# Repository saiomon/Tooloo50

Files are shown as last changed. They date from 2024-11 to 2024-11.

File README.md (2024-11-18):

# Tooloo50
Töölöö50 is 40% tadpole mount keyboard with arrow cluster/40%TKL/numpad.

## Layout
Supports iso/ansi enter, split right shift, wk/wkl, a few bottom row options and 4x3 grid on the right hand side extension.
töölöö50

## Case
3DP case files support some of the possible combinations.
render
vid

### Hardware list
| Item | Amount |
| --- | --- |
| Tadpole | 8 |
| M2.5 10mm | 2 |
| M2.5 16mm (CS)  | 2 |
| M2.5 6mm  (CS) | 2 |
| M2.5 Heat insert, OD 3.5mm | 6 |

*Countersunk (CS)

## PCB
PCB supports mx switches, and additionally 4-key hall sensors on wasd for HE option. STM32F072 processor, ESD protection, fuse, smd USB. Possibility for external flash and crystal. KiCad files and production files are included.
TooLooMX

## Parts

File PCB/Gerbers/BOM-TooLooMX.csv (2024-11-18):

Comment | Designator | Footprint | LCSC
100k | R3,R4 | R_0805_2012Metric | C149504
10n | C9 | C_0402_1005Metric | C15195
100n | C1,C11,C13,C14,C15,C16,C17,C18,C19,C20,C21,C22,C23,C4,C5 | C_0402_1005Metric | C1525
TYPE-C-31-M12 | J1 | USB_C_Receptacle_Hroparts_TYPE-C-31-M-12 | C165948
220 | R14,R15 | R_0805_2012Metric | C17557
D_Schottky | D63 | D_SOD-123F | C18199087
2N7002K | Q1 | SOT-23 | C22379475
10k | R10,R11,R12,R13,R9 | R_0402_1005Metric | C25744
51k | R6 | R_0402_1005Metric | C25794
1.5k | R5 | R_0402_1005Metric | C25867
4.7k | R1,R2 | R_0402_1005Metric | C25900
5.1k | R7,R8 | R_0805_2012Metric | C27834
1u | C2,C3 | C_0805_2012Metric | C28323
SLSS49E-3 | HALL1,HALL2,HALL3,HALL4 | SOT-23 | C2904393
STM32F401-LQFP64 | U2 | LQFP-64_10x10mm_P0.5mm | C46046
1u | C8 | C_0402_1005Metric | C52923
MCP1700T-3302E/TT | U1 | SOT-23 | C5446
mSMD110-16V | F1,F2,F3 | Fuse_1812_4532Metric | C69691
10u | C10 | CP_EIA-3216-10_Kemet-I_Pad1.58x1.35mm_HandSolder | C7171
1N4148W | D1,D10,D11,D12,D13,D14,D15,D16,D17,D18,D19,D2,D20,D21,D22,D23,D24,D25,D26,D27,D28,D29,D3,D30,D31,D32,D33,D34,D35,D36,D37,D38,D39,D4,D40,D41,D42,D43,D44,D45,D46,D47,D48,D49,D5,D50,D51,D52,D53,D54,D55,D56,D57,D58,D59,D6,D60,D61,D7,D8,D9 | D_SOD-123 | C81598
SRV05-4-P-T7 | U3 | SOT-23-6-routable | C85364
RB060M-60TR SS34 | D62 | D_SMA | C8678

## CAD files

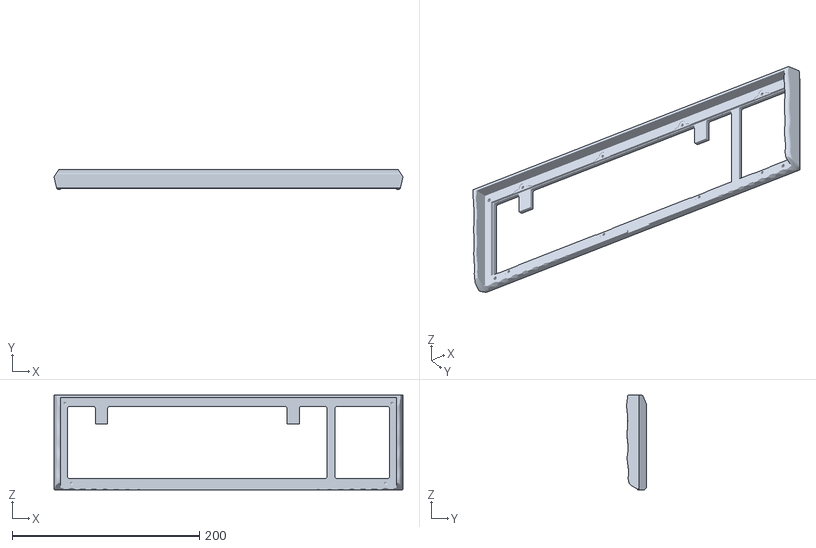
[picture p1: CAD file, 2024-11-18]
Case/stl/TopWKL_FullGrid.stl
373.0 x 21.3 x 101.2

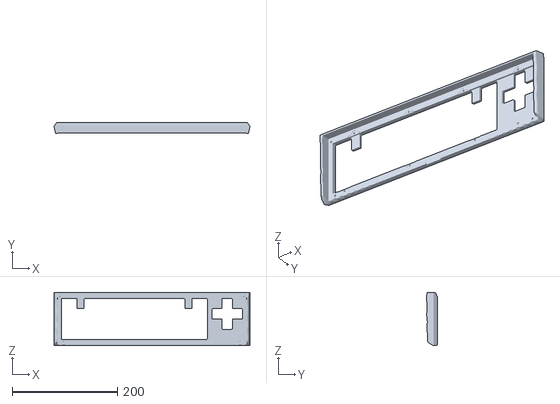
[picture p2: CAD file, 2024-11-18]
Case/stl/TopWKL_Arrows.stl
373.0 x 21.3 x 101.2

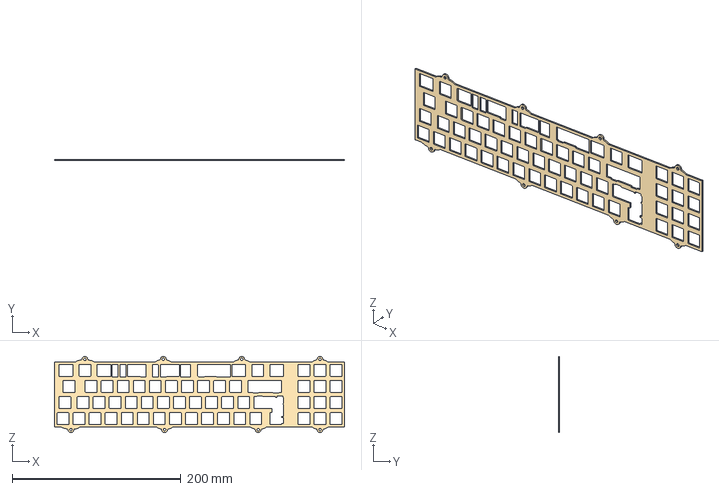
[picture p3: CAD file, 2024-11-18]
Case/step/plate.step
343.9 x 1.60 x 90.3 mm

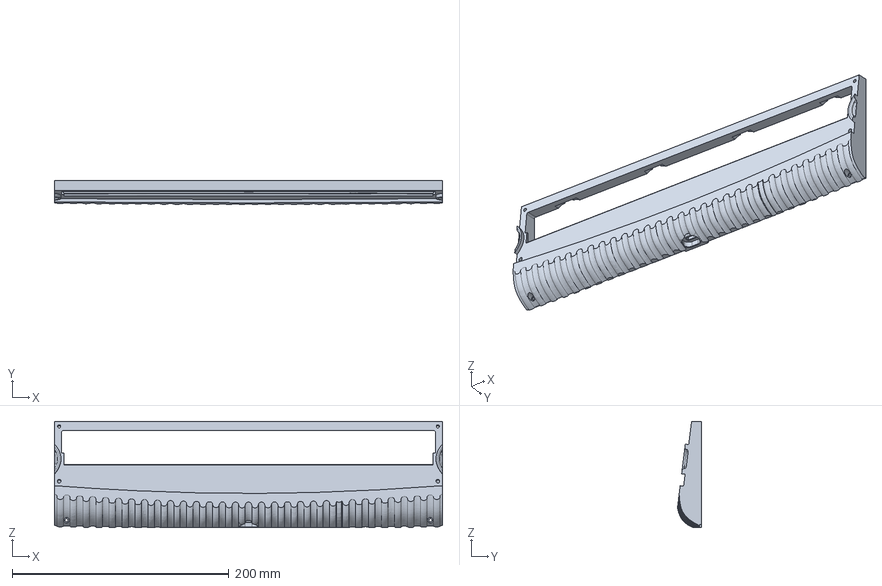
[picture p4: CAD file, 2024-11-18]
Case/step/Bottom.step
358.1 x 22.3 x 98.3 mm

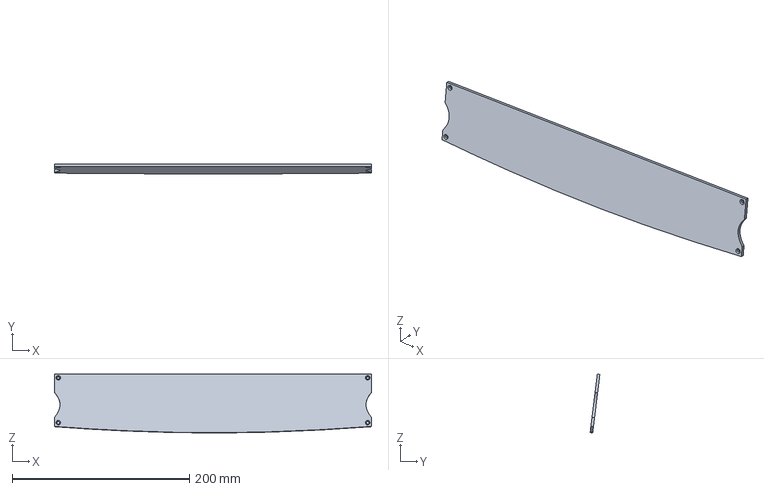
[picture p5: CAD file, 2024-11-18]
Case/step/Weight.step
358.1 x 11.1 x 66.6 mm

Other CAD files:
Case/step/TopTKL_FullGrid.step
Case/step/TopWKL_TKL.step
Case/step/TopTKL_arrows.step
Case/stl/TopWKL_TKL.stl
Case/stl/Weight.stl

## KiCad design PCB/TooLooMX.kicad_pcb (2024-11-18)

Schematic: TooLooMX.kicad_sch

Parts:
BOOT1: Jumper_2_Open; SolderJumper-2_P1.3mm_Open_Pad1.0x1.5mm
BZ1: Buzzer; MagneticBuzzer_PUI_AT-0927-TT-6-R; not fitted
C1, C4: 100n; C_0402_1005Metric; Manufacturer Part Number CC0402KRX7R8BB104
C2, C3: 1u; C_0805_2012Metric; Manufacturer Part Number CC0805KKX7R8BB105
C5, C11, C13, C15, C16, C17, C18, C19, C20, C21, C22, C23: 100n; C_0402_1005Metric
C6, C7: 16p; C_0402_1005Metric; not fitted
C8: 1u; C_0402_1005Metric
C9: 10n; C_0402_1005Metric
C10: 10u; CP_EIA-3216-10_Kemet-I_Pad1.58x1.35mm_HandSolder; Manufacturer Part Number TAJA106K016RNJ
C12: 4.7u; C_0402_1005Metric; not fitted
C14: 100n; C_0402_1005Metric; Manufacturer Part Number CL05B104KB54PNC
D1, D2, D3, D4, D5, D6, D7, D8, D9, D10, D11, D12, D13, D14, D15, D16, D17, D18, D19, D20, D21, D22, D23, D24, D25, D26, D27, D28, D29, D30, D31, D32, D33, D34, D35, D36, D37, D38, D39, D40, D41, D42, D43, D44, D45, D46, D47, D48, D49, D50, D51, D52, D53, D54, D55, D56, D57, D58, D59, D60, D61: 1N4148W; D_SOD-123; Manufacturer Part Number 1N4148W
D62: RB060M-60TR SS34; D_SMA; Manufacturer Part Number RB060M-60TR SS34
D63: D_Schottky; D_SOD-123F
F1, F2, F3: mSMD110-16V; Fuse_1812_4532Metric; Manufacturer Part Number mSMD110-16V
FB1: CBW201209U121T; L_0805_2012Metric; Manufacturer Part Number CBW201209U121T
HALL1, HALL2, HALL3, HALL4: SLSS49E-3; SOT-23
J1: TYPE-C-31-M12; USB_C_Receptacle_Hroparts_TYPE-C-31-M-12; Manufacturer Part Number TYPE-C-31-M-12
M1: Motor_DC; Buzzer_15x7.5RM7.6; not fitted
NRST1: Jumper_2_Open; SolderJumper-2_P1.3mm_Open_Pad1.0x1.5mm
Q1: 2N7002K; SOT-23
Q2: TIP120; TO-220-3_Vertical; not fitted
R1, R2: 4.7k; R_0402_1005Metric
R3, R4: 100k; R_0805_2012Metric; Manufacturer Part Number RC0805FR-07100KL
R5: 1.5k; R_0402_1005Metric
R6: 51k; R_0402_1005Metric
R7, R8: 5.1k; R_0805_2012Metric; Manufacturer Part Number RC0805FR-075K1L
R9: 10k; R_0402_1005Metric; Manufacturer Part Number 0402WGF1002TCE
R10, R11, R12, R13: 10k; R_0402_1005Metric
R14, R15: 220; R_0805_2012Metric
S1: MX_stab; STAB_MX_P_10u
S2, S4: MX_stab; STAB_MX_P_3u
S3: MX_stab; STAB_MX_P_2.25u
S5: MX_stab; STAB_MX_2u
S6: MX_stab; STAB_MX_P_2.75u
S7: MX_stab; STAB_MX_2.75u
S8: MX_stab; STAB_MX_2.25u
S9: MX_stab; STAB_MX_P_ISO-ROT
SW1, SW2, SW3, SW4, SW5, SW6, SW7, SW8, SW9, SW10, SW11, SW12, SW13, SW14, SW15, SW16, SW18, SW20, SW21, SW22, SW23, SW24, SW25, SW26, SW27, SW28, SW29, SW30, SW31, SW32, SW33, SW34, SW35, SW37, SW38, SW39, SW40, SW41, SW42, SW43, SW44, SW45, SW46, SW47, SW49, SW50, SW51, SW56, SW57, SW58, SW62, SW63, SW64, SW67, SW68, SW69: CPG151101S11; SW_MX_1u; Manufacturer Part Number CPG151101S11
SW17, SW48, SW65, SW66, SW70, SW71: CPG151101S11; SW_MX_1.5u; Manufacturer Part Number CPG151101S11
SW19, SW52, SW53, SW54, SW55, SW59, SW60, SW61: CPG151101S11; SW_MX_1.25u; Manufacturer Part Number CPG151101S11
SW36: CPG151101S11; SW_MX_1.75u; Manufacturer Part Number CPG151101S11
U1: MCP1700T-3302E/TT; SOT-23; Manufacturer Part Number MCP1700T-3302E/TT
U2: STM32F401-LQFP64; LQFP-64_10x10mm_P0.5mm
U3: SRV05-4-P-T7; SOT-23-6-routable; Manufacturer Part Number USBLC6-2SC6
U4: BL24C256A-SFRC; TSSOP-8_4.4x3mm_P0.65mm; Manufacturer Part Number BL24C256A-SFRC; not fitted
X1: ARM JTAG; PinHeader_2x5_P2.54mm_Vertical_Staggered
X2: LED; PinHeader_1x2_P2.54mm_Vertical
Y1: 7325-0800A2010-00; Crystal_SMD_3225-4Pin_3.2x2.5mm; Manufacturer Part Number 7325-0800A2010-00; not fitted

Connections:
3V3: BOOT1.1 (A), C1.2, C3.1, C4.1, C5.2, C8.1, C9.1, C10.1, C11.2, C13.2, C15.2, C17.2, C19.2, C21.2, C23.2, D62.2 (A), HALL1.1 (VDD), HALL2.1 (VDD), HALL3.1 (VDD), HALL4.1 (VDD), R1.1, R2.1, R4.1, R5.1, R6.1, U1.2 (VO), U2.1 (VBAT), U2.13 (VDDA/VREF+), U2.19 (VDD), U2.32 (VDD), U2.48 (VDD), U2.64 (VDD), U4.8 (VCC), X1.7, X1.8
5V: C2.1, D62.1 (K), D63.1 (K), F1.2, M1.1 (+), R3.1, U1.3 (VI)
AI0: C16.1, R10.1, U2.24 (PC4)
AI1: C18.1, R11.1, U2.25 (PC5)
AI2: C20.1, R12.1, U2.26 (PB0/TIM3_CH3)
AI3: C22.1, R13.1, U2.27 (PB1/TIM3_CH4)
BOOT0: BOOT1.2 (B), R9.2, U2.60 (BOOT0), X1.5
BUZ: R15.1, U2.41 (USART1_CK/TIM1_CH1/PA8)
C0: SW1.1, SW2.1, SW19.1, SW36.1, U2.23 (PA7/SPI1_MOSI/TIM3_CH2)
C1: SW3.1, SW20.1, SW37.1, SW53.1, SW65.1, U2.22 (PA6/TIM3_CH1/SPI1_MISO)
C2: SW4.1, SW21.1, SW38.1, SW54.1, U2.21 (PA5/TIM2_CH1/SPI1_SCK)
C3: SW5.1, SW22.1, SW39.1, SW55.1, SW66.1, U2.20 (PA4/USART2_CK)
C4: SW6.1, SW23.1, SW40.1, SW56.1, SW67.1, U2.17 (PA3/TIM2_CH4/USART2_RX)
C5: SW7.1, SW24.1, SW41.1, U2.2 (PC13)
C6: SW8.1, SW25.1, SW42.1, SW57.1, SW68.1, U2.3 (PC14/OSC32_IN)
C7: SW9.1, SW26.1, SW43.1, U2.4 (PC15/OSC32_OUT)
C8: SW10.1, SW27.1, SW44.1, SW58.1, SW69.1, U2.8 (PC0)
C9: SW11.1, SW28.1, SW45.1, U2.16 (PA2/TIM2_CH3/USART2_TX)
C10: SW12.1, SW29.1, SW46.1, SW59.1, SW70.1, U2.15 (PA1/TIM2_CH2/USART2_RTS)
C11: SW13.1, SW30.1, SW47.1, SW52.1, SW60.1, U2.14 (PA0/TIM2_CH1/USART2_CTS)
C12: SW17.1, SW18.1, SW31.1, SW35.1, SW48.1, SW61.1, SW71.1, U2.39 (USART6_CK/TIM3_CH3/PC8)
C13: SW14.1, SW32.1, SW49.1, SW62.1, U2.57 (SPI1_MOSI/SPI3_MOSI/TIM3_CH2/PB5)
C14: SW15.1, SW33.1, SW50.1, SW63.1, U2.56 (NJTRST/SPI1_MISO/SPI3_MISO/I2C3_SDA/TIM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)
C15: SW16.2, SW34.2, SW51.2, SW64.2, U2.55 (JTDO-SWO/SPI1_SCK/SPI3_SCK/I2C2_SDA/TIM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)
D+: J1.A6 (D+), J1.B6 (D+), R5.2, U2.45 (OTG_FS_DP/USART6_RX/PA12), U3.1 (IO1)
D-: J1.A7 (D-), J1.B7 (D-), U2.44 (OTG_FS_DM/TIM1_CH4/USART6_TX/PA11), U3.3 (IO2)
GND: BZ1.2 (-), C1.1, C2.2, C3.2, C4.2, C5.1, C6.2, C7.2, C8.2, C9.2, C10.2, C11.1, C12.1, C13.1, C14.2, C15.1, C16.2, C17.1, C18.2, C19.1, C20.2, C21.1, C22.2, C23.1, FB1.1, HALL1.2 (GND), HALL2.2 (GND), HALL3.2 (GND), HALL4.2 (GND), J1.A1 (GND), J1.B1 (GND), NRST1.1 (A), Q1.2 (S), Q2.3 (E), R3.2, R4.2, R7.1, R8.1, R9.1, U1.1 (GND), U2.12 (VSSA/VREF-), U2.18 (VSS), U2.31 (VSS), U2.47 (VSS), U2.63 (VSS), U3.2 (VN), U4.1 (A0), U4.2 (A1), U4.3 (A2), U4.4 (GND), U4.7 (WP), X1.3, X1.4, X1.10, X2.2, Y1.2, Y1.4
GNDPWR: FB1.2, J1.S (SHIELD)
LED_PWM: U2.9 (PC1), X2.1
NRST: C14.1, NRST1.2 (B), U2.7 (NRST), X1.9
unnamed: BZ1.1 (+), R15.2
unnamed: D1.2 (A), SW1.2
unnamed: D2.2 (A), SW2.2
unnamed: D3.2 (A), SW3.2
unnamed: D4.2 (A), SW4.2
unnamed: D5.2 (A), SW5.2
unnamed: D6.2 (A), SW6.2
unnamed: D7.2 (A), SW7.2
unnamed: D8.2 (A), SW8.2
unnamed: D9.2 (A), SW9.2
unnamed: D10.2 (A), SW10.2
unnamed: D11.2 (A), SW11.2
unnamed: D12.2 (A), SW12.2
unnamed: D13.2 (A), SW13.2
unnamed: D14.2 (A), SW14.2
unnamed: D15.2 (A), SW15.2
unnamed: D16.2 (A), SW16.1
unnamed: D17.2 (A), SW17.2, SW18.2
unnamed: D18.2 (A), SW19.2
unnamed: D19.2 (A), SW20.2
unnamed: D20.2 (A), SW21.2
unnamed: D21.2 (A), SW22.2
unnamed: D22.2 (A), SW23.2
unnamed: D23.2 (A), SW24.2
unnamed: D24.2 (A), SW25.2
unnamed: D25.2 (A), SW26.2
unnamed: D26.2 (A), SW27.2
unnamed: D27.2 (A), SW28.2
unnamed: D28.2 (A), SW29.2
unnamed: D29.2 (A), SW30.2
unnamed: D30.2 (A), SW31.2, SW35.2
unnamed: D31.2 (A), SW32.2
unnamed: D32.2 (A), SW33.2
unnamed: D33.2 (A), SW34.1
unnamed: D34.2 (A), SW36.2
unnamed: D35.2 (A), SW37.2
unnamed: D36.2 (A), SW38.2
unnamed: D37.2 (A), SW39.2
unnamed: D38.2 (A), SW40.2
unnamed: D39.2 (A), SW41.2
unnamed: D40.2 (A), SW42.2
unnamed: D41.2 (A), SW43.2
unnamed: D42.2 (A), SW44.2
unnamed: D43.2 (A), SW45.2
unnamed: D44.2 (A), SW46.2
unnamed: D45.2 (A), SW47.2, SW52.2
unnamed: D46.2 (A), SW48.2
unnamed: D47.2 (A), SW49.2
unnamed: D48.2 (A), SW50.2
unnamed: D49.2 (A), SW51.1
unnamed: D50.2 (A), SW53.2, SW65.2
unnamed: D51.2 (A), SW54.2
unnamed: D52.2 (A), SW55.2, SW66.2
unnamed: D53.2 (A), SW56.2, SW67.2
unnamed: D54.2 (A), SW57.2, SW68.2
unnamed: D55.2 (A), SW58.2, SW69.2
unnamed: D56.2 (A), SW59.2, SW70.2
unnamed: D57.2 (A), SW60.2
unnamed: D58.2 (A), SW61.2, SW71.2
unnamed: D59.2 (A), SW62.2
unnamed: D60.2 (A), SW63.2
unnamed: D61.2 (A), SW64.1
unnamed: D63.2 (A), M1.2 (-), Q1.3 (D), Q2.2 (C)
unnamed: HALL1.3 (VOUT), R10.2
unnamed: HALL2.3 (VOUT), R11.2
unnamed: HALL3.3 (VOUT), R12.2
unnamed: HALL4.3 (VOUT), R13.2
unnamed: J1.A5 (CC1), R7.2
unnamed: J1.B5 (CC2), R8.2
unnamed: Q1.1 (G), Q2.1 (B), R14.2
unnamed: R6.2, U2.43 (USART1_RX/TIM1_CH3/PA10)
unnamed: C12.2, U2.30 (VCAP1)
PA9: U2.42 (USART1_TX/TIM1_CH2/PA9)
PB2/BOOT1: U2.28 (PB2), X1.6
PB13: U2.34 (SPI2_SCK/I2S2_CK/PB13)
R0: D2.1 (K), D3.1 (K), D4.1 (K), D5.1 (K), D6.1 (K), D7.1 (K), D8.1 (K), D9.1 (K), D10.1 (K), D11.1 (K), D12.1 (K), D13.1 (K), D14.1 (K), D15.1 (K), D16.1 (K), D17.1 (K), U2.51 (SPI3_SCK/I2S3_CK/PC10)
R1: D18.1 (K), D19.1 (K), D20.1 (K), D21.1 (K), D22.1 (K), D23.1 (K), D24.1 (K), D25.1 (K), D26.1 (K), D27.1 (K), D28.1 (K), D29.1 (K), D30.1 (K), D31.1 (K), D32.1 (K), D33.1 (K), U2.52 (SPI3_MISO/PC11)
R2: D34.1 (K), D35.1 (K), D36.1 (K), D37.1 (K), D38.1 (K), D39.1 (K), D40.1 (K), D41.1 (K), D42.1 (K), D43.1 (K), D44.1 (K), D45.1 (K), D46.1 (K), D47.1 (K), D48.1 (K), D49.1 (K), U2.61 (I2C1_SCL/TIM4_CH3/TIM10_CH1/PB8)
R3: D1.1 (K), D50.1 (K), D51.1 (K), D52.1 (K), D53.1 (K), D54.1 (K), D55.1 (K), D56.1 (K), D57.1 (K), D58.1 (K), D59.1 (K), D60.1 (K), D61.1 (K), U2.62 (I2C1_SDA/TIM4_CH4/TIM11_CH1/PB9)
RGB_3V3: U2.36 (SPI2_MOSI/PB15)
SCL: R2.2, U2.58 (I2C1_SCL/USART1_TX/TIM4_CH1/PB6), U4.6 (SCL)
SDA: R1.2, U2.59 (I2C1_SDA/USART1_RX/TIM4_CH2/PB7), U4.5 (SDA)
SOL: R14.1, U2.50 (JTDI/TIM2_CH1/PA14)
SWCLK: U2.49 (JTCK-SWCLK/PA14), X1.2
SWDIO: U2.46 (JTMS-SWDIO/PA13), X1.1
VBUS: F1.1, J1.A4 (VBUS), J1.B4 (VBUS), U3.5 (VP)
XTAL_IN: C7.1, U2.5 (PH0/OSC_IN), Y1.3
XTAL_OUT: C6.1, U2.6 (PH1/OSC_OUT), Y1.1

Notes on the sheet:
Spooky pin (*)
SWITCH MATRIX
EEPROM
3V3
(*) "Spooky pins": on STM32F4x1, pins A9 and B2 cannot be used for switch matrix: - A9 is meant to be used as a VBUS sensing. It has a undocumented internal pulldown resistor; - B2 is used as BOOT1 during bootup, so it needs an external pulldown for successful bootup; - B13 is locked by the SPI dri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

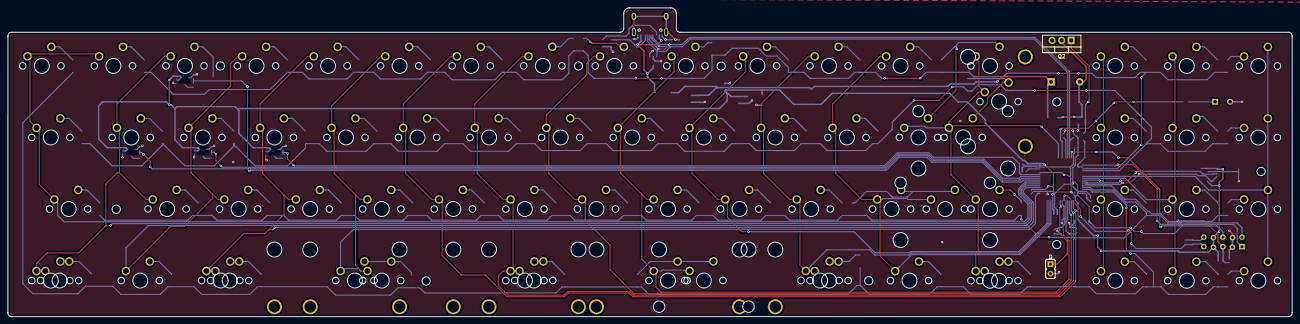
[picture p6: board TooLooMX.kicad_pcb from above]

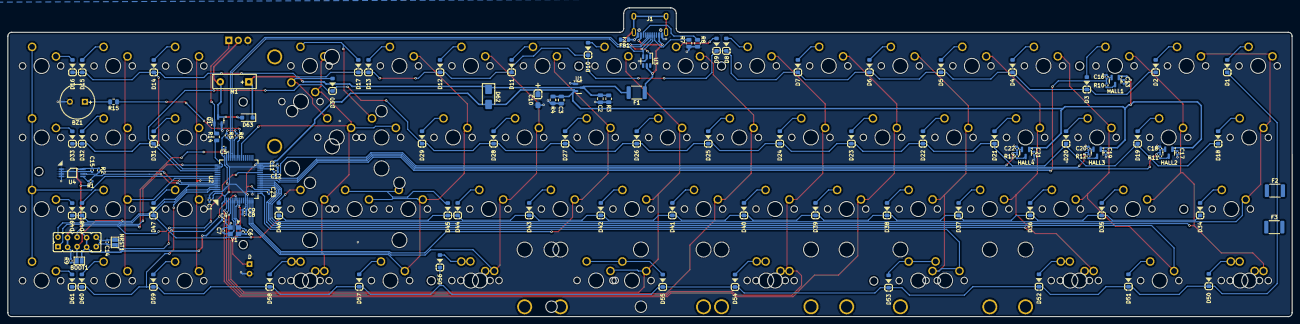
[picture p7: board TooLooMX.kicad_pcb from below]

Board: 2 copper layers, 341.9 x 82.2 mm, 203 parts (121 on the bottom side), 115 nets.
